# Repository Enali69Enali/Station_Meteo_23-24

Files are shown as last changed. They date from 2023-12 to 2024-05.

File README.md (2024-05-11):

# Station_Meteo_23-24
## Description du projet
Pour le cours de projet d'électronique lors de la 4e année du cycle d'ingénieur en alternance, celui ci réalise une girouette pour la station météo d'une ruche connectée. 
Une girouette est un objet de mesure pour nous donner la direction du vent. Ce projet reprend le projet Github 2022-2023 : [Station_Meteo_2022-2023](https://github.com/Solene49000/Station_Meteo_2022-2023). 
Dans ce projet, leur systeme de girouette n'était pas fonctionnelle, du à des differences de tensions trop faible par rapport au différente position de la fleche de la girouette. Nous proposons donc une solution alternative à ce probleme avec notre projet. 

Ce projet de station météo comporte plusieurs composants tels que:
- La quantité de pluie tombée 
- La vitesse du vent 
- La luminosité
- La température 
- L'humidité
Mais nous nous concentrons surtout sur la direction du vent avec la girouette. 

Pour voir la présentation du projet en cours, cliquez [ici](https://github.com/Enali69Enali/Station_Meteo_23-24/blob/master/rapport_de_s%C3%A9ance/Premier%20pr%C3%A9sentation%20%C3%A9lectronique.pdf).

## Fonctionnement
La première question à laquelle nous avons du repondre est : **Comment connaitre la direction de vent sans utilisé la premiere méthode ?** 
Le difference de tension est une bonne méthode mais devait etre plus importante pour faire fonctionner le projet. 
Nous sommes donc partis sur une idée de CODE GRAY (1 bit se change à la fois) avec 4 entrée. Pour avoir une seule sortie nous avons utilisé un réseau R2R.
### Le projet physique
Pour simuler le CODE GRAY, nous avons pensé à une idée de LED émettrices et photo-transitors récepteurs séparer par un tourniquet fait en impression 3D. Quand il y aura le passage d'un trou (pas de matiere), les photo-transitor recevront la lumière infrarouge. Sinon rien ne sera perçu.
Voici les principales impressions 3D nécessaire pour le projet :
* [Boite maintenant le PCB](https://github.com/Enali69Enali/Station_Meteo_23-24/blob/master/modelisation_3D/boite.stl) (Attention dans le fichier .stl il manque un trou pour faire passer les câbles que nous avons rajoutés en en faisant un dans le fond de la boite avec un fer à souder. Pour les autres modifications regarder [ici](#petits-défaut-à-améliorer-pour-le-bon-fonctionnement-du-projet))
* [Couvercle](https://github.com/Enali69Enali/Station_Meteo_23-24/blob/master/modelisation_3D/cylindre%20led-couvercle.stl) (Attention le PCB a un sens sinon celui ci ne passera pas avec le couvercle)
* [Réajusteur pour le roulement](https://github.com/Enali69Enali/Station_Meteo_23-24/blob/master/modelisation_3D/calle%20roulement.stl)
* Fleche de la girouette nous avait été déja fournis

Pour le montage, il suffit de collé le réajusteur pour le roulement sur la tige de la boite, puis de placé un roulement adapté pour emboité le couvecle et la boite. Les impressions sont fait pour des roulements aux dimensions de : diamètre extérieur 22mm, diamètre intérieur 8mm et diamètre de hauteur 7mm.

En plus a été designé un cache pour séparer LEDs/ photo-transistors les uns des autres (voir [le rapport du jour 13/03 de PELLETIER](https://github.com/Enali69Enali/Station_Meteo_23-24/blob/master/rapport_de_s%C3%A9ance/Rapport13_03_2024PELLETIER.pdf)). Ceux ci n'ont pas encore été testé.

### Le projet électronique
#### Hardware
Le [PCB](https://github.com/Enali69Enali/Station_Meteo_23-24/blob/master/BoardsEAGLE/R2R_v2.1.brd) contenant le réseau R2R doit être imprimés (si vous ne l'avez pas déjà) et ajouté avec chaque composant.
Pour les LEDs et photo-transistors il faut que ceux ci soit soudé au dos de la carte avec la tete reposant sur le plastique du PCB pour être à la même hauteur tous, pour le passage dans le tourniquet soit synchronisé. 
Les LED et phototransistors travaillent sur la même longueur d'onde, cad 940 nm (infrarouge). Les phototransistors sont utilisés en emmeteur commun avec un inverseur MOS à sa sortie afin d'avoir réellement 0 ou 3.3V et pas de valeurs entre pour le bon fonctionnement du réseau R2R. L'angle de réception des phototransistors a été choisi le plus petit possible (et disponible), cad 28º, afin de limiter le plus possible les parasites des autre leds.

#### Software
Un fois téléversé, le programme rentre en light sleep et se réveille toute les 15 secondes (ou si reception d'une goutte de pluie), ce
qui permet d'obtenir la position de la girouette
Il y a 16 position differentes, Ouest etant la plus petite, tous les phototransistors recevant tous de la lumière et Nord etant la plus grande, tous les transistors etant cachés.
Actuellement, le valeurs sont complètement à refaire: la courbe n'étant pas linéaire et les valeurs ayant été déterminées avec le PCB de test, les écarts entre les valeurs sont trop grand et les résultats étaient au final mieux que prévu.
Le code de la girouette reste extrêmement simple, etant juste un else-if

## Installation
Préparer le modèle de la girouette physique avec le PCB à l'intérieur.
Il faut brancher le cable micro USB à l'ordinateur pour pouvoir téléverser le code mais voir aussi les informations envoyées par la girouette
Ensuite il faut alimenter la girouette en 3.3V: le fil rouge doit être branché au 3.3V et le fil noir au GND.
Pour vérifier que le montage fonctionne bien, environs 170 mA sont "consommés" par notre montage et sont donc visible sur le générateur
de tension

## Utilisation
Nous avons decidé pour nos tests que le N serait pointé à la position 0 0 0 0 (tous les phototransistors ne recoivent pas de rayonnement des LEDs).
Lors du lancement du programme, celui ci retournera toutes les 15 secondes la direction de la girouette. Le projet n'a pas encore été testé en rajoutant l'anémomètre.

## Petits défaut à améliorer pour le bon fonctionnement du projet
- Les calles du PCB dans la boite ne sont pas exactement aligné, il faut la bloqué avec du scotch en exemple et la surélever pour que les LEDs/photo-transistors soient au niveau des trous pour laisser le passage des rayons. Conseil : si vous voulez résoudre ce soucis avant l'impression de la boite, vous devez surélever le fond de la boite de 2-3 mm;
- Les valeurs theoriques recues par la carte sont différentes de la réalité, il faut donc réajuster les valeurs pour la bonne gestion de la direction de la girouette;
- Les séparateurs peuvent être imprimés si ils y a trop d'interférence.

## Auteurs et remerciments
Projet réalisé par DUEE-MOREAU Arwen et PELLETIER Ilane en classe ELSE4 cursus Polytech FISA 4 année sur le semestre 7 et 8 avec l'aide du professeur PETER Christian.

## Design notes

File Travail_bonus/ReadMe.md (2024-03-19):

Travail supplémentaire fait en plus du projet.
Sujet principale : Module ESP32 LoRa

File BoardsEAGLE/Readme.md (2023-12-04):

Ici sont stockées les dessin cartes (schematics, boards).

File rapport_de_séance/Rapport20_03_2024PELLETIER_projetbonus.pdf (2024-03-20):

# Rapport de séance n°13

Séance spéciale : aide pour un autre groupe

Séance du 20/03/2024

## Objectif de la séance : Réalisation des modèles 3D

Continuer sur le travail bonus en attendant notre carte.

## Réalisé pendant la séance

Notre problème semble venir de l’initialisation du récepteur qui sors une erreur lors de la fonction begin(). Nous avons changé les programmes émetteur et récepteur (trouvé directement dans les exemple fourni sur l’application Arduino).

https://forum.arduino.cc/t/lora-modulefails-on-first-time-init/1015518 (https://forum.arduino.cc/t/lora-module-fails-on-first-time-init/1015518)

Nous avons remarqué que les pins n’était pas initialisé donc nous les initialisons.

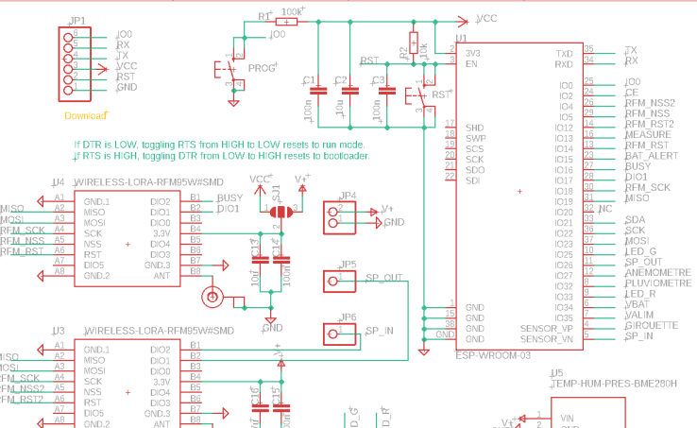
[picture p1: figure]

En initialisant, le Sender fonctionne mais pas de Receiver.

Documentation eps32 :
https://www.espressif.com/sites/default/files/documentation/esp32-wroom-32_datasheet_en.pdf. (https://www.espressif.com/sites/default/files/documentation/esp32-wroom-32_datasheet_en.pdf)

Documentation LoRa CC68 :
https://www.manualslib.com/manual/2618644/Nicerf-Lora-Cc68.html?page=5#manual. (https://www.manualslib.com/manual/2618644/Nicerf-Lora-Cc68.html?page=5#manual)

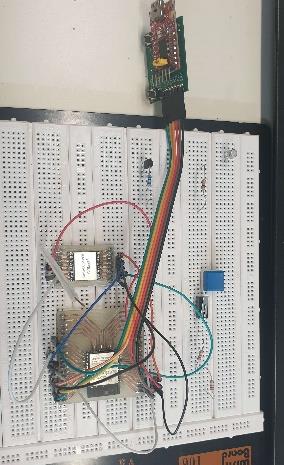
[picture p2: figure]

Avec les documentations si dessus j’ai pu rebrancher les modules (voir photo). Après avoir bien remis le RX et TX, nous téléversons le code du récepteur. Malheureusement nous retombons sur notre erreur d’initialisation « Starting LoRa failed ! ». Nous devons surement avoir un soucis dans l’initialisation des pins.

## Problèmes de la séance

Problème avec le petit PCB pour remplacer le module LoRa causant une erreur lors du téléversement du code.

## A faire attention

Bien branché le mini USB. Mettre la même fréquence en émission et réception.

## A faire à la prochaine séance

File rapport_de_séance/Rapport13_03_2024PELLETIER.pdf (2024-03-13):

# Rapport de séance n°11

Séance du 13/03/2024

## Objectif de la séance : Réalisation des modèles 3D

Finir le PCB et l’envoyer, designer le cache.

## Réalisé pendant la séance

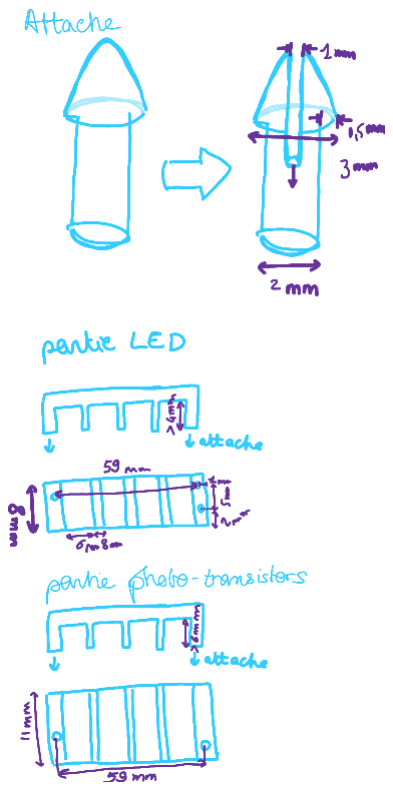
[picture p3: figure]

J’ai commencé la séance par terminer le PCB pour pouvoir le faire imprimer rapidement.

J’ai finis de redécaler les emplacement de LEDs et phototransistors pour pouvoir caller les composants au dos du PCB « collé ». J’ai également placer les trous pour fixer les caches.

Nous avons générer les fichiers geber pour pouvoir envoyer à l’usine la fabrication de notre PCB.

Passons au cache sur FreeCad.

J’ai pensé à un système d’attache pour fixer le cache au-dessus des LEDs ou des phototransistors.

Apres avoir pris toutes les mesures j’ai pu commencer la modélisations des caches.

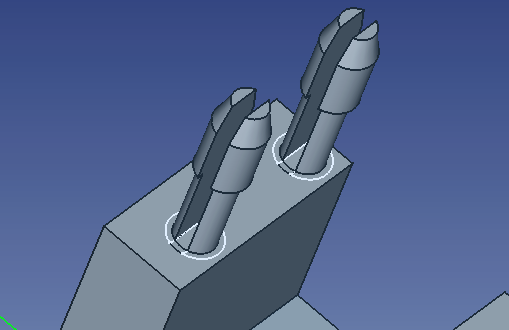
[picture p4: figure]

Vous pouvez retrouvez ces pièces en fichiers .stl directement sur GitHub.

## Problèmes de la séance

## A faire attention

Les attaches sont seulement faites en théorie, jamais tester en conditions réelles.

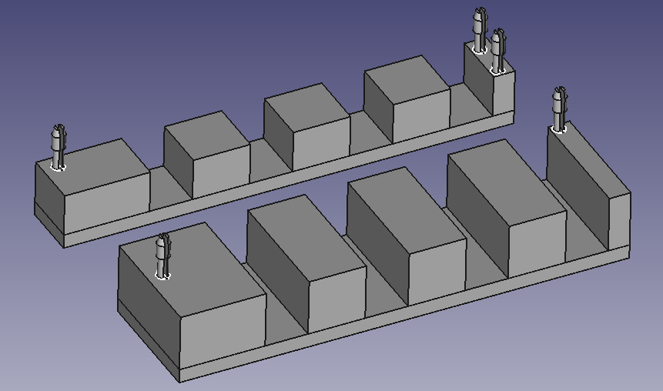
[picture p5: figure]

## A faire à la prochaine séance

Imprimer les caches et trouer la boite (que nous avons oublier de trou pour faire passer le câble.

Si nous avons reçu le composant nous pourrons aussi souder sur le PCB les composants.

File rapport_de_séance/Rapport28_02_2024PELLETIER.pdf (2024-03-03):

# Rapport de séance n°10

Séance du 28/02/2024

## Objectif de la séance : Réalisation des modèles 3D

Récupérer les impressions 3D, finir le dessin Layout et faire le design 3D cache.

## Réalisé pendant la séance

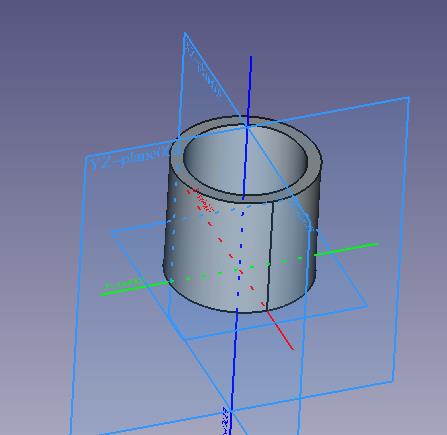
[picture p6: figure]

Au début de la séance j’ai récupéré les impressions 3D finit et passer un peu de temps a retirer les supports (long car il y avait des supports pour chaque interstice de LED). Dans le couvercle, le roulement c’est parfaitement emboité ((on ne peut plus le retirer). Malheureusement, j’ai étais trop prévoyant pour la boite et il y avait trop de jeu entre la tige et le roulement.

J’ai donc designer et imprimer une nouvelle petite pièce pour empêcher cet écart.

Apres l’impression, je l’ai colle avec la colle chaude sur le pic principal de la boite.

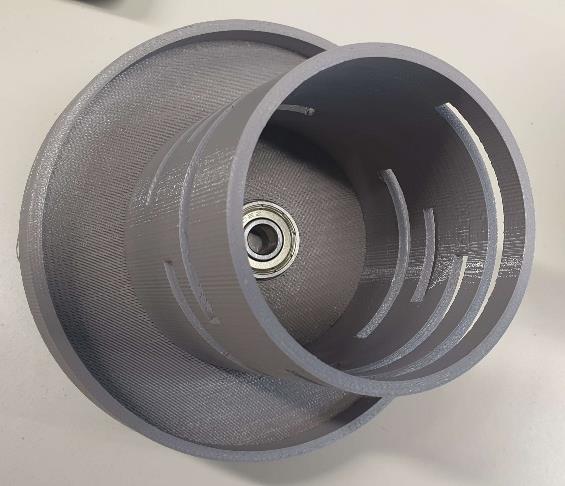
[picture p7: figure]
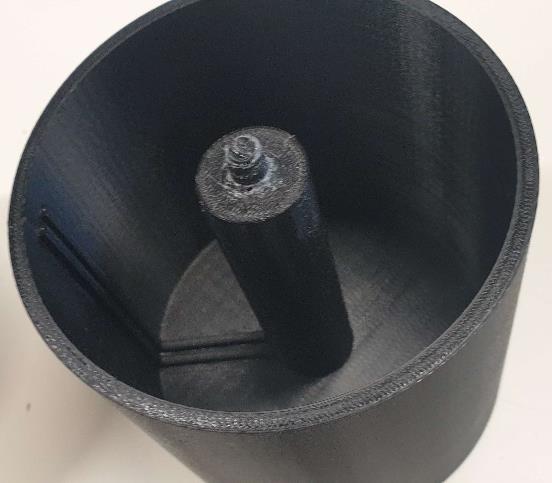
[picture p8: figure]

J’ai également retravailler la pointe qui permet de
fixer la girouette avec une soufflette d’air chaud (car celle-ci c’était déformé lors de l’impression a cause du poids et de la chaleur).

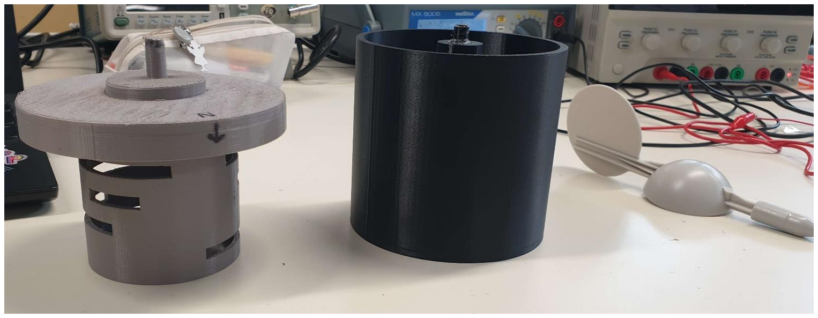
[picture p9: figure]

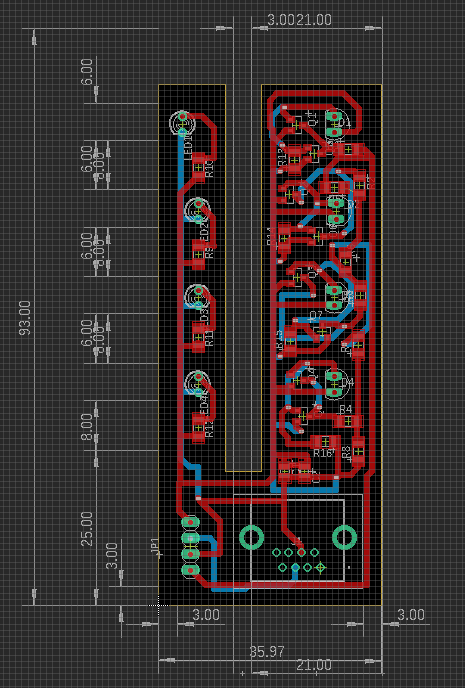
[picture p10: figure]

Apres avoir finit de travailler les impressions, je me suis remis sur le design du Lay-out du PCB du réseaux R2R.

J’ai finit par arriver a ce résultat, en faisant attention entre la distance des chemin et le placement des LEDs/phototransistors.

J’ai rajouté les trous dans le PCB et souder des éléments pour que ma camarade avance.

## Problèmes de la séance

N’aies pas eu beaucoup de temps pour travailler sur le cache.

## A faire attention

Ne pas oublier les trous dans le PCB.

## A faire à la prochaine séance

Finir le PCB et l’envoyer, designer le cache.

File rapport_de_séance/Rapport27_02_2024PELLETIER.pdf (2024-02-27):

# Rapport de séance n°10

Séance du 27/02/2024

## Objectif de la séance : Réalisation des modèles 3D

Récupérer les valeurs des dimensions des roulements pour modifier les impressions 3D en conséquences et pouvoir imprimer et continuer voire finir le design du PCB.

## Réalisé pendant la séance

Durant la séance, j’ai pu finir la modélisation des pièces (boite et couvercle) avec les mesures du nouveau roulement.

Apres avoir fait ces modifications, j’ai lancé les impressions qui seront normalement finies pour le prochain cours.

Je me suis remis sur la modification du layout avec les nouveau distances du PCB.

Nous avons une largeur maximale de 36mm.

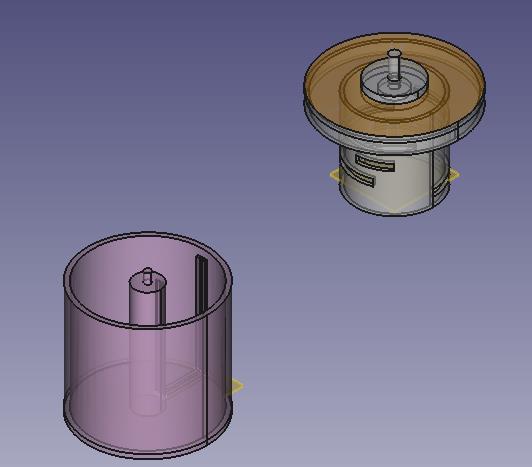
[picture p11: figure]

En étudiant la question, nous devrons « coller » les LEDs et phototransistors d’un cote de la carte et les composants de l’autre.

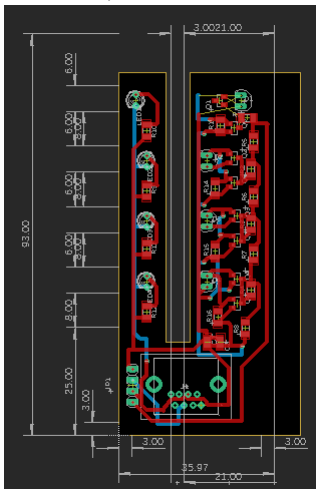
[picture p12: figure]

## Problèmes de la séance

Ne pas avoir laisser assez d’espace pour le placement des LEDs et phototransistors.

## A faire attention

De même.

## A faire à la prochaine séance

Finir le dessin Layout et faire le design 3D cache.

Diamètre extérieur | 22 mm
Diamètre intérieur | 8 mm
Hauteur | 7 mm

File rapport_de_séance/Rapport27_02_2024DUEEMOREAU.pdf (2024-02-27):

Comme les problèmes de la séance précédente ont été résolu (en par4e), j’ai pu réaliser les mesures.
Nous obtenons ce tableau :

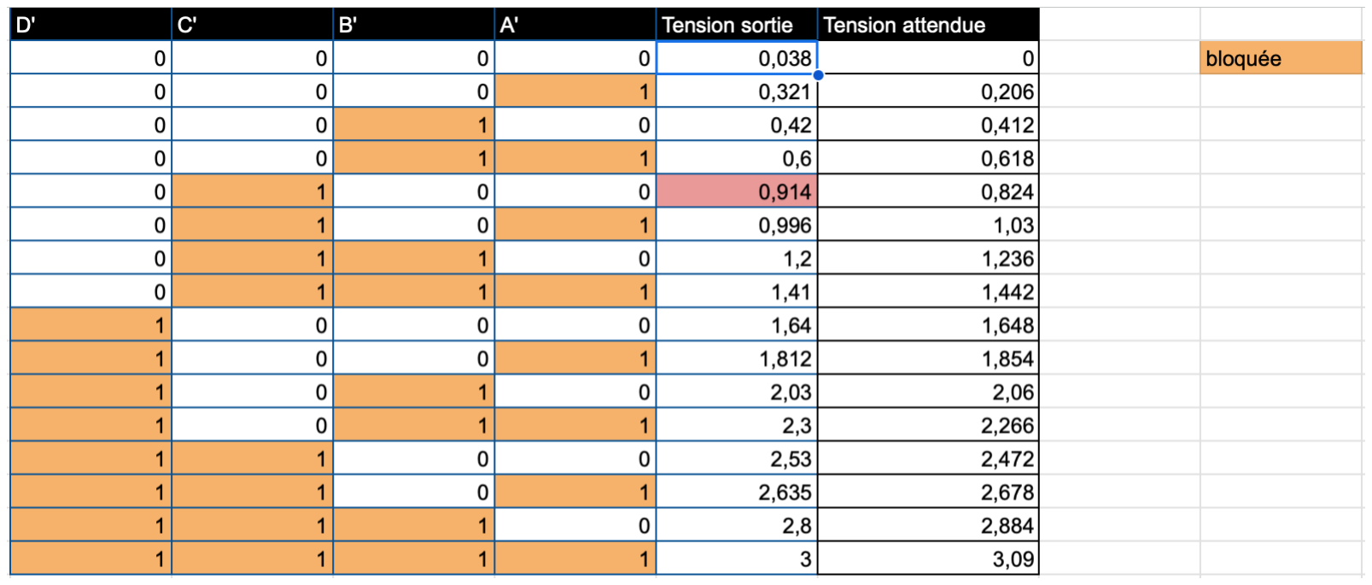
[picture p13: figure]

La led A étant le lsb et la D le msb.

Les valeurs obtenues sont légèrement différentes à cause des problèmes de soudure. Nous pouvons donc en conclure que le réseau marche pour notre projet.

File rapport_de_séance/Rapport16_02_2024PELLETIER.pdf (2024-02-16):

# Rapport de séance n°9

Séance du 16/02/2024

## Objectif de la séance : Réalisation des modèles 3D

Récupérer l’impression 3D, retravailler le PCB.

## Réalisé pendant la séance

L’impression terminée, j’ai retiré tous supports créer pour l’impression. Puis comme le plateau a été imprimer avec des supports j’ai utilisé une soufflette chauffante pour faire refondre le dessus pour permettre sa fixation. Le rendu n’est pas parfait mais celui-ci tient.

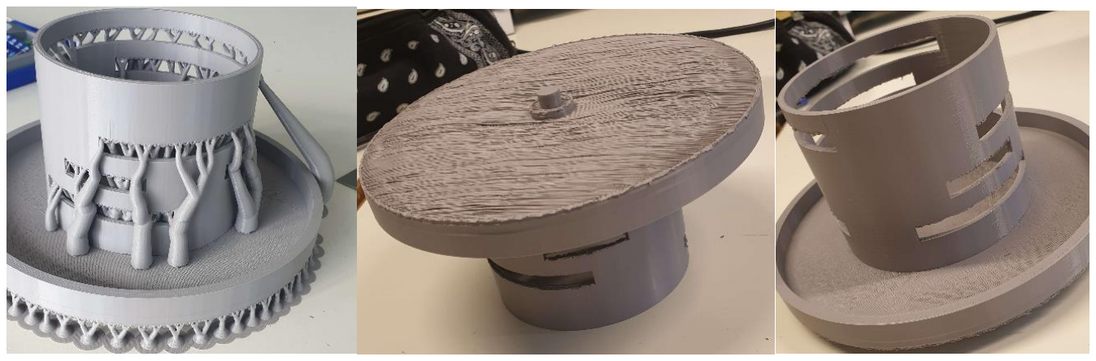
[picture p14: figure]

Malheureusement, en sorti d’impression nous nous rendons compte :

- De sa taille par rapport au système. Celui-ci est surement un peu trop grand en largeur. Nous réduirons donc certains paramètres de taille pour la prochaine impression ;
- Qu’il faudra utiliser un roulement plus gros pour supporter le système ;
- Que la queue de la girouette ne passe pas en hauteur.

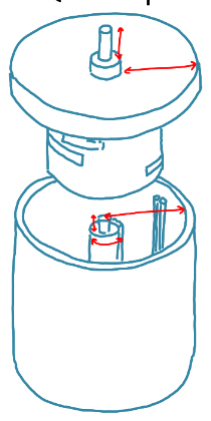
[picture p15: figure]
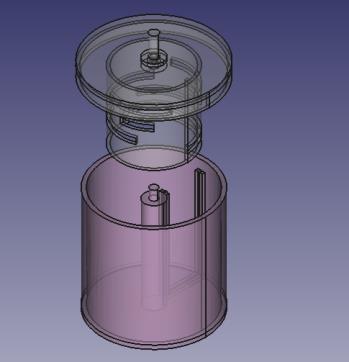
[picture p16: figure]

Les fichiers modifiés ont été ajouté sur le Github du projet.

J’ai également commencé à modifier les dimensions du PCB sur EAGLE.

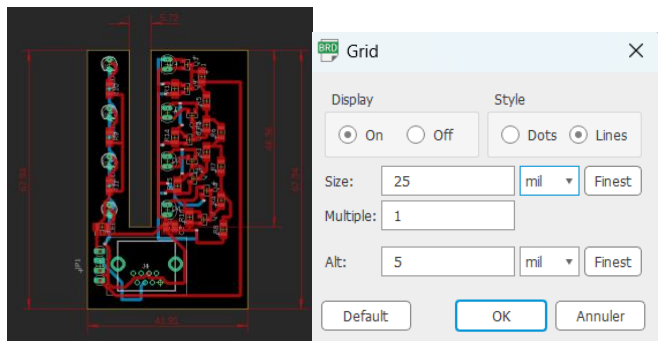
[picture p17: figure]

Avant :

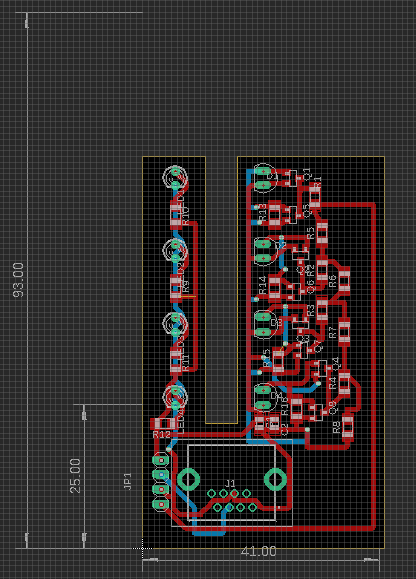
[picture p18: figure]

Début de la prise de mesure :

## Problèmes de la séance

Un composant du PCB test ne fonctionnais pas donc j’ai du resouder certains composant pour aider ma camarade à avancer sur les tests.

## A faire attention

Au soudure qui se défont rapidement sur ce PCB test, à la taille du roulement pour l’impression et à l’unité lors du design sur la board EAGLE.

## A faire à la prochaine séance

Récupérer les valeurs des dimensions des roulements pour modifier les impressions 3D en conséquences et pouvoir imprimer et continuer voire finir le design du PCB.

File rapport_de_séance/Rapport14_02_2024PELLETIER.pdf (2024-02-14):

# Rapport de séance n°8

Séance du 14/02/2024

## Objectif de la séance : Réalisation des modèles 3D

Lancer l’impression 3D, test.

## Réalisé pendant la séance

Après avoir tester, nous nous sommes aperçu avec l’aide de notre professeur que la LED n’avait pas assez de courant pour émettre avec 3V3. Notre résistance était initialement à 100kΩ.

Les tests réalisés :

Valeurs de résistances | 100kΩ | 47Ω | 33kΩ
Avec émission de la LED | 3.22 V | 3.2 V | 3.24 V
Sans réception de photorécepteurs | 0.2 V | 0.008 V | 0.006 V

Nous choisissons la 33kΩ car elle nous affiche des résultats satisfaisant (proche de3V3) et que nous en avons en stocks.

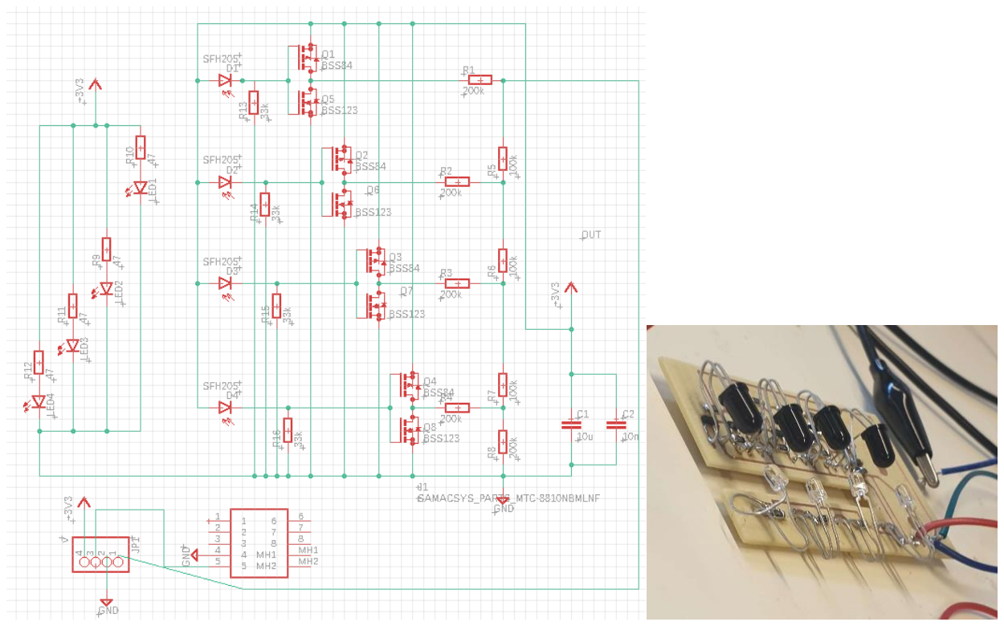
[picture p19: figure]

Un problème supplémentaire qui s’est rajouté que nous n’avions pas remarqué avant : les vias de ce PCB ne sont pas métallisé. J’ai donc du couper des pattes de composant pour combler les trous et donc relier la partie supérieur de la carte avec celle inférieur.

Après avoir tout resouder, nous avons tester et nous avons 3.0V et 0.3V.

## Problèmes de la séance

Une partie de la piste c’est dessoudé, j’ai dû donc m’arranger pour tirer la patte d’une LED pour combler le manque.

## A faire attention

## A faire à la prochaine séance

Tester la première impression 3D

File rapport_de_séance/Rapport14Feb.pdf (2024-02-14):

Pendant la séance, nous avons dû revoir les valeurs des résistances du PCB.
Nous avons remarqué que nous avions mis 100k Ohms au niveau des diodes au lieu de 230 Ohms, ce qui faisait que le courant dans la diode était trop faible (qui devait être de 100 mA). Nous avons finalement uHlisé 47 Ohms afin d’avoir 100 mA dans les diodes.

Coté phototransistor, nous avons aussi réajustés la résistance à l’émeNeur pour passer de 100k à 33k car les résultats obtenus sur la plaque à trous étaient meilleurs. On devait être sur que les tensions de seuils des transistors P et N étaient aNeint avec la nouvelle valeur de résistance.

Le schéma diode-transistor est donc :

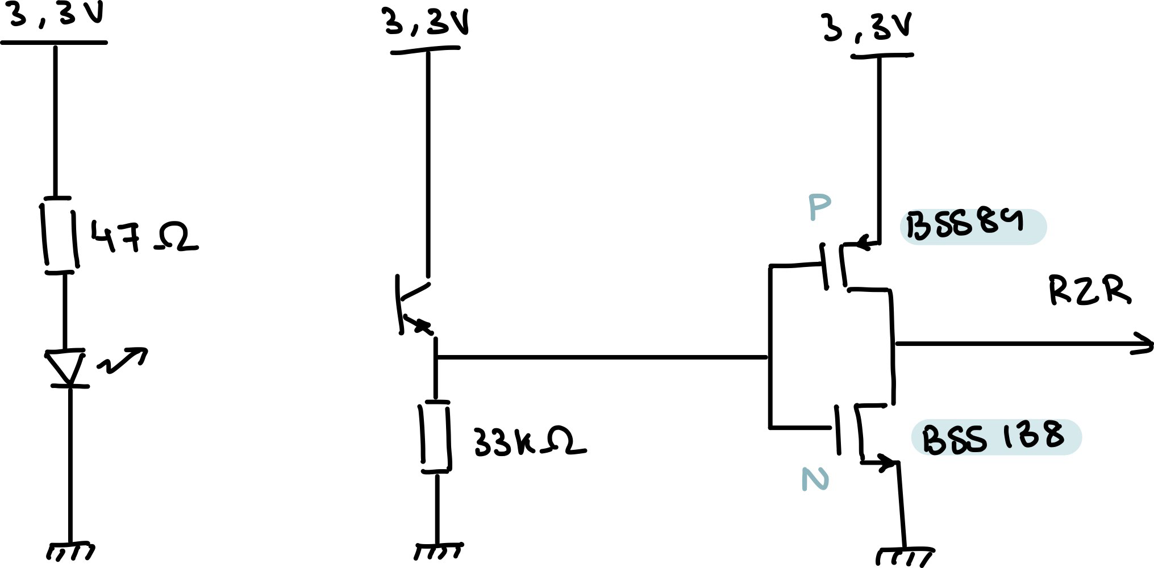
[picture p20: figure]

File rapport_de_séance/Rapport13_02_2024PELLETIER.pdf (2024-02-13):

# Rapport de séance n°7

Séance du 13/02/2024

## Objectif de la séance : Réalisation des modèles 3D

Souder sur le PCB les composants du schéma et faire la soutenance de milieu de projet.

## Réalisé pendant la séance

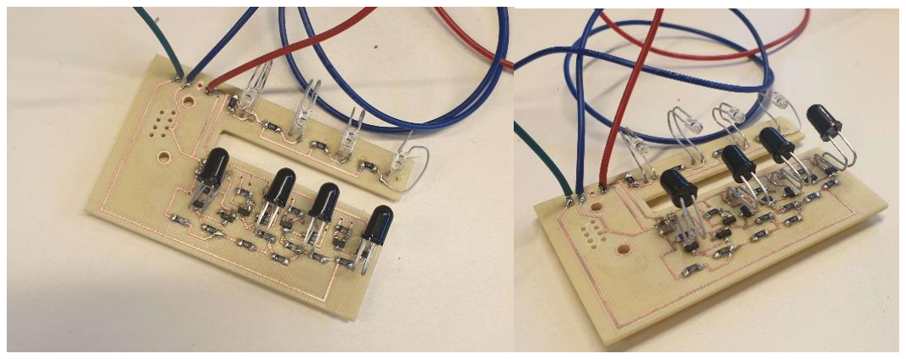
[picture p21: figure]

J’ai pu souder les composant en faisant attention au composant et leur valeur. C’était un travail long et minutieux. Il fallait aussi faire attention au sens des LED et capteurs infrarouges.

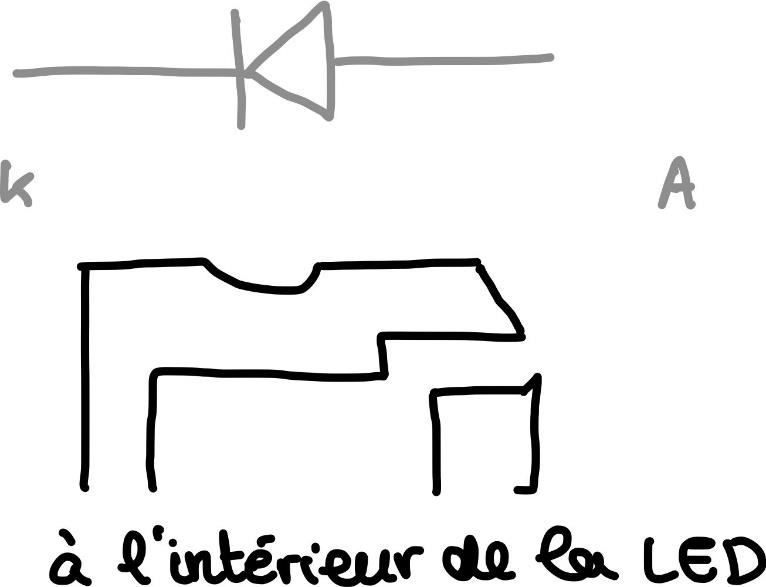
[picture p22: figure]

## Problèmes de la séance

Une partie de la piste c’est dessoudé, j’ai dû donc m’arranger pour tirer la patte d’une LED pour combler le manque.

## A faire attention

## A faire à la prochaine séance

Tester et mettre a imprimer la première pièce en 3D.

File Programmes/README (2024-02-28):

Fichiers du projet précédent avec les modifications apportées par notre groupe cette année

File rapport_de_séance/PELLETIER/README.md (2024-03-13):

Rapport de séance de l'étudiant Ilane PELLETIER.

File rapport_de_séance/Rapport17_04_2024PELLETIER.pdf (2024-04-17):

# Rapport de séance n°15

Séance du 17/04/2024

## Objectif de la séance : Réalisation des modèles 3D

Aider Arwen avec les tests puis commencer a faire les slides.

## Réalisé pendant la séance

Malheureusement, à la dernière séance, il y avait des petits soucis de transmission. A l’aide de pate a modeler nous avons pu déterminer que la carte était trop basse par rapport au fente du code gray (mettre la pate a modeler sur la fente de la carte puis mettre le couvercle, celle-ci laisse une marque de la hauteur de la fente). Nous avons du nous y prendre de cette manière car la boite totalement opaque nous empêchera de savoir son placement interne.

Nous avons vu qu’il nous manquait 2 mm de hauteur, donc nous l’avons rehausser avec du scotch plié.

Le reste de la séance, je l’ai consacré a commencer les slides de la présentation finale.

## Problèmes de la séance

## A faire attention

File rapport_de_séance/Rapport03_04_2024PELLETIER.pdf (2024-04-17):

# Rapport de séance n°14

Séance du 03/04/2024

## Objectif de la séance : Réalisation des modèles 3D

Souder et monter notre girouette.

## Réalisé pendant la séance

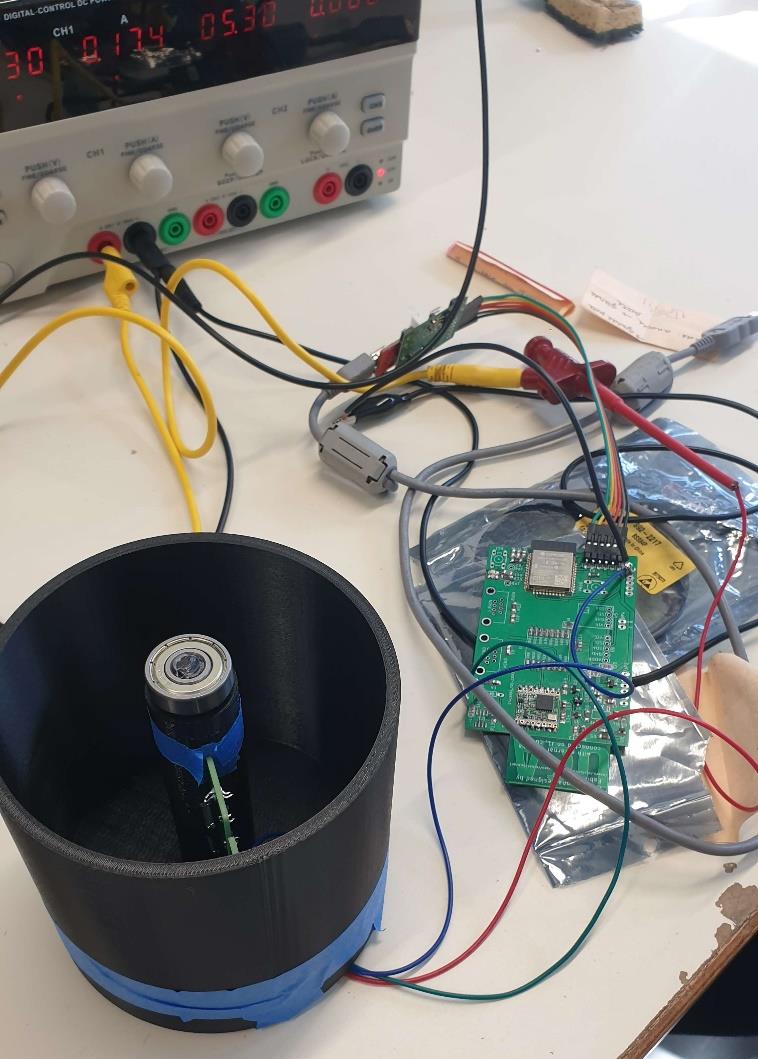
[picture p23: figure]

Après que la pâte thermique soit positionner sur le PCB par le professeur, j’ai installé les composant 1 à 1 pour passer la carte au four.

Sortie du four, j’ai installé les composants LEDs et photo-transistors et je les soudé.

(en m’assurant que ceci soit face a face)

Arwen a testé le système, puis je l’ai installé dans la boite dans laquelle j’ai fait un trou.

Malheureusement, il y a des petits soucis de transmission que nous règlerons a la prochaine séance.

## Problèmes de la séance

Soucis dans la dernière étape.

## A faire attention

## A faire à la prochaine séance

Faire fonctionner le tout.

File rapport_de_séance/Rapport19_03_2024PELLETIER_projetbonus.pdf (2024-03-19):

# Rapport de séance n°12

Séance spéciale : aide pour un autre groupe

Séance du 19/03/2024

## Objectif de la séance : Réalisation des modèles 3D

Comme je ne pouvais pas avancer sur notre projet car nous n’avions pas la carte pour commencer les premier test, j’ai commencé à rédiger un script pour un autre groupe de projet : des scripts pour des ESP32 avec modulo LoRa.

## Réalisé pendant la séance

Avec des documentations d’internet (https://randomnerdtutorials.com/ttgo-lora32-sx1276-arduinoide/) (https://randomnerdtutorials.com/ttgo-lora32-sx1276-arduino-ide/) et nos propres codes déjà fournis dans notre projet j’ai pu commencer à écrire.

Etape 1 : Initialisation des modules (pris du projet de l’année dernière de la station météo)

Etape 2 : connexion au module (choisir le bon port)

Etape 3 : Test d’envoi d’une string

Plusieurs problèmes sont arrivés a partir de cet instant, je suis arrivé à recevoir quelques caractère mais ne correspondant pas forcément à ceux envoyé puis je ne recevais plus rien. En ajoutant des logs pour savoir ou es ce que je me situe, j’ai pu remarqué que je me situais bloqué a la fin d’une fonction. J’ai l’impression que les module n’arrive pas à se connecter entre eux.

Les codes ont été posés sur GitHub dans le dossier Travail_bonus/.

## Problèmes de la séance

Problèmes cités au-dessus

## A faire attention

## A faire à la prochaine séance

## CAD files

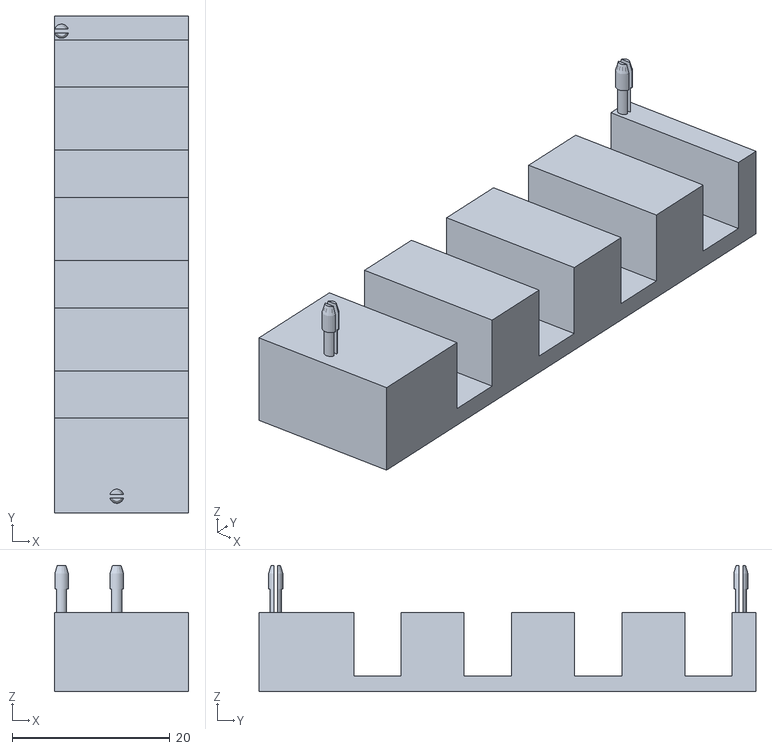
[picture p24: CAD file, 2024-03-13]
modelisation_3D/cylindre led-cache ptT.stl
17.0 x 63.0 x 16.0

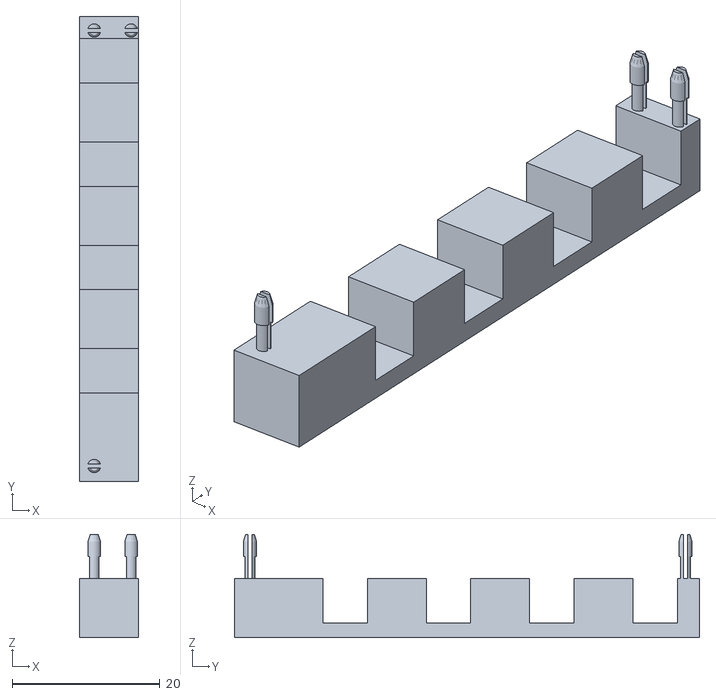
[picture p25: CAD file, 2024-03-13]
modelisation_3D/cylindre led-cache LED.stl
8.00 x 63.0 x 14.0

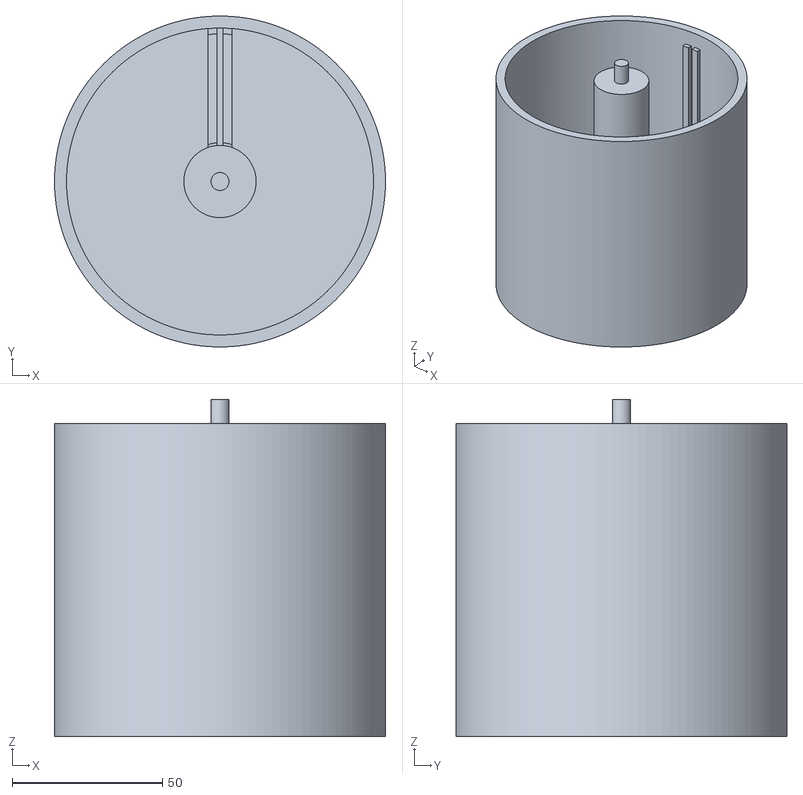
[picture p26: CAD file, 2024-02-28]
modelisation_3D/boite.stl
110.0 x 110.0 x 112.0

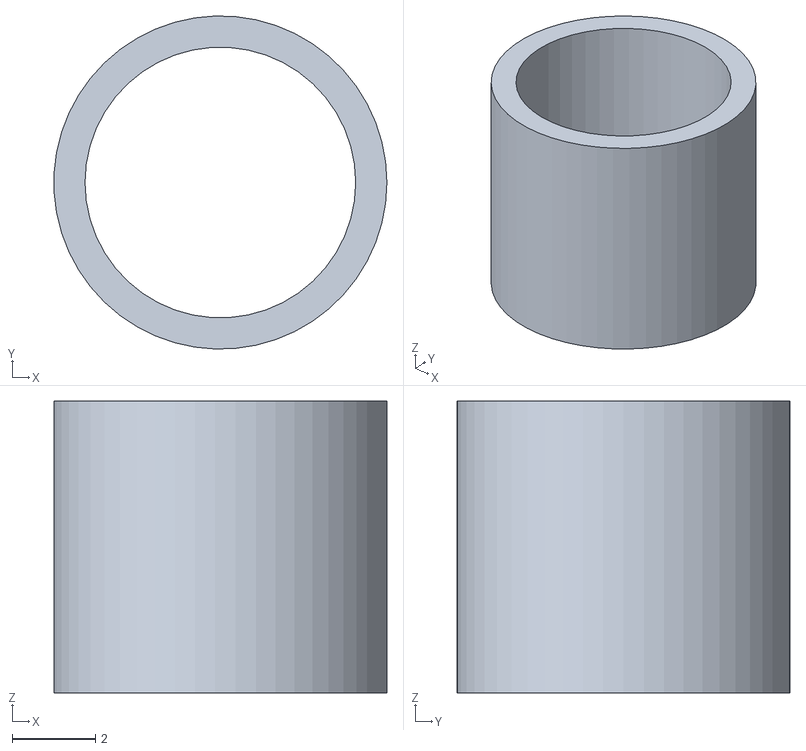
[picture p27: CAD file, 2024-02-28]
modelisation_3D/calle roulement.stl
7.99 x 8.00 x 7.00

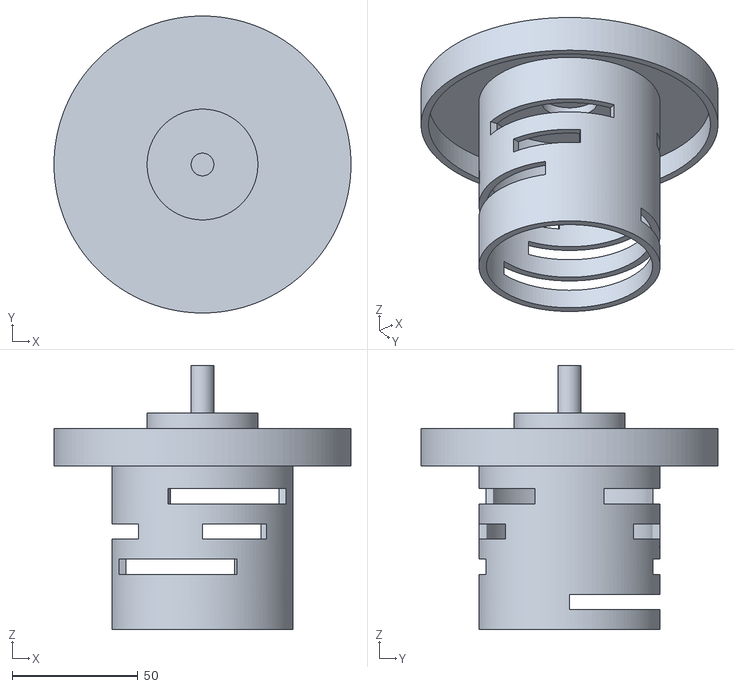
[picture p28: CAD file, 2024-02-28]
modelisation_3D/cylindre led couvercle.stl
118.0 x 118.0 x 105.0

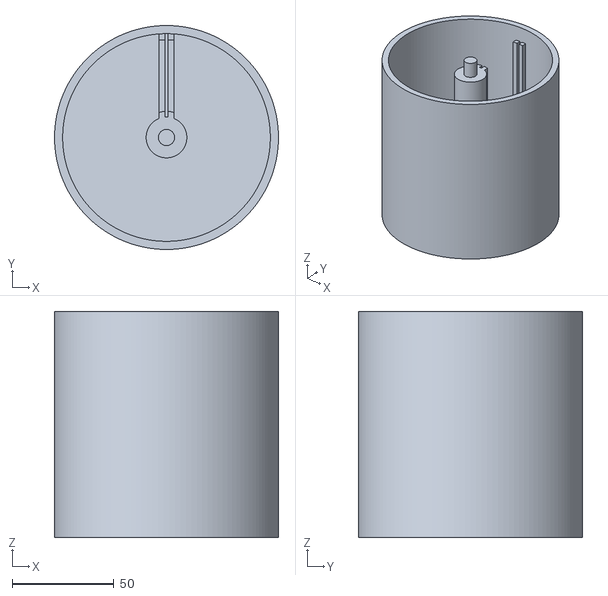
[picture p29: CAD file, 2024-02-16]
modelisation_3D/cylindre led-boite.stl
110.0 x 110.0 x 111.0

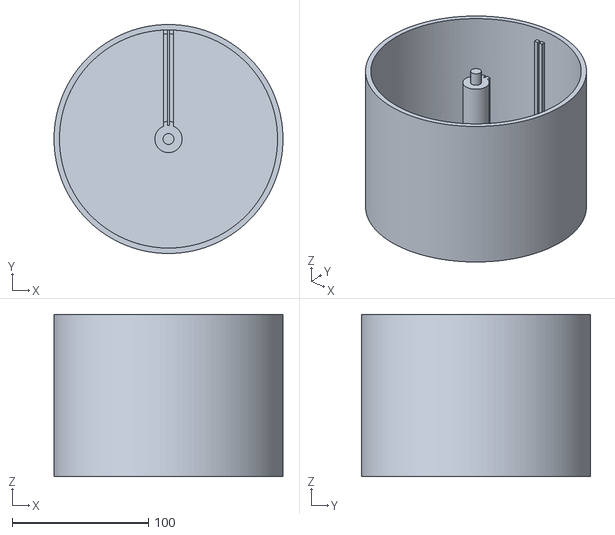
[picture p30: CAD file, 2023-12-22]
modelisation_3D/boite pcb-Body.stl
168.0 x 167.9 x 119.0

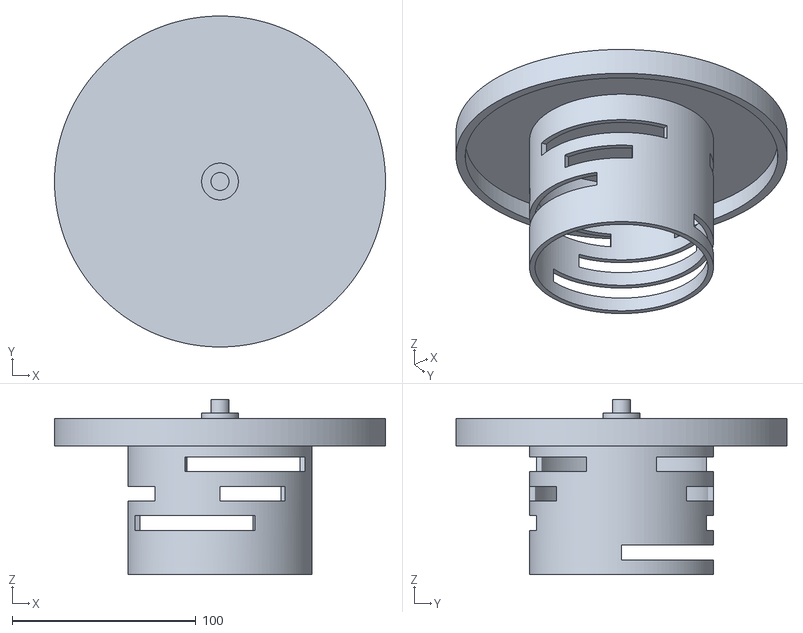
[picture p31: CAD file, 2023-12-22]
modelisation_3D/couvercle cylindre led-Body.stl
180.0 x 179.9 x 95.2

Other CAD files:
modelisation_3D/v2_modelisation_grille_code_gray.stl
modelisation_3D/v1_modelisation_grille_code_gray.stl
modelisation_3D/cylindre led-couvercle.stl

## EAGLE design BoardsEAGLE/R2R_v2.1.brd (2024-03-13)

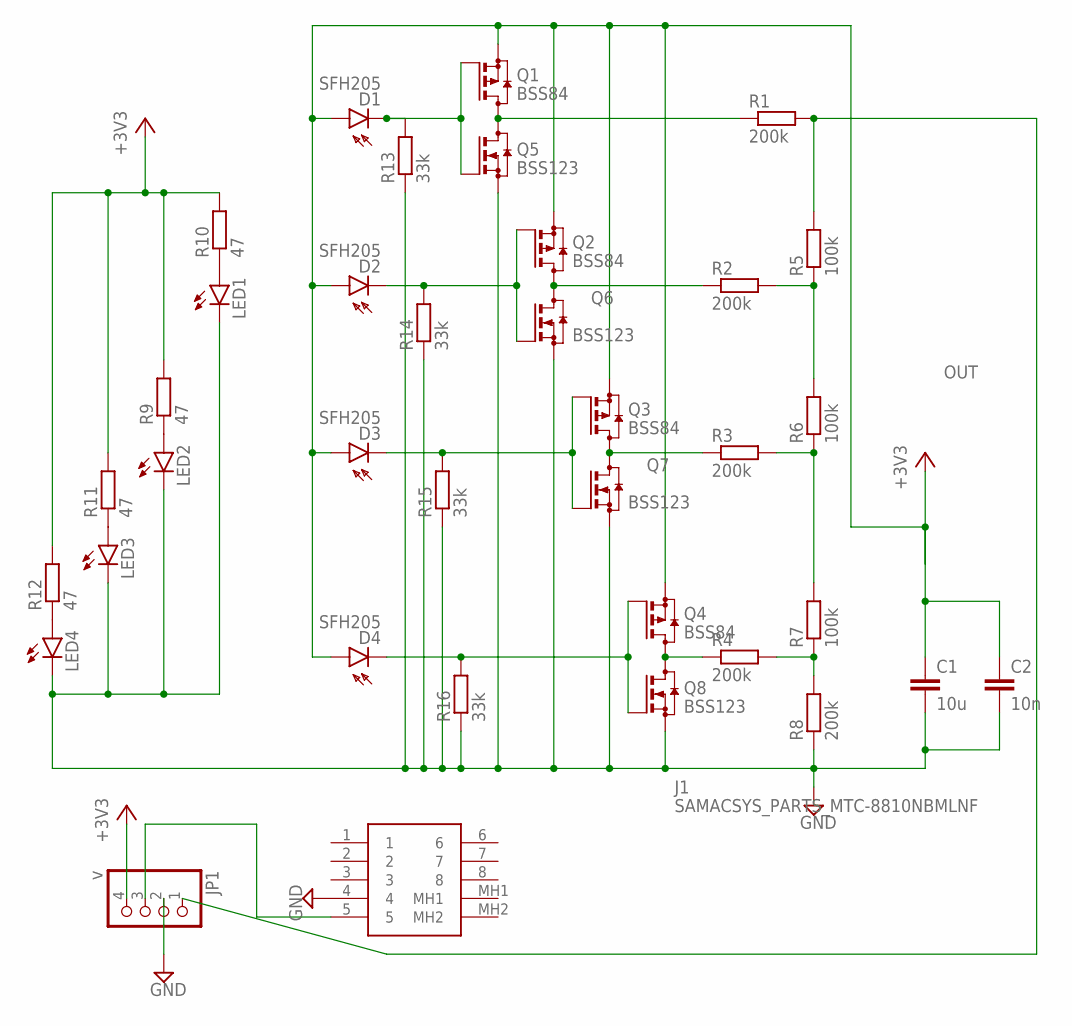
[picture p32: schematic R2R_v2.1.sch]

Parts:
C1: 10u; C0805
C2: 10n; C0805
D1, D2, D3, D4: SFH205
J1: SAMACSYS_PARTS_MTC-8810NBMLNF; SAMACSYS_PARTS_MTC8810NBMLNF
JP1: v; 1X04
LED1, LED2, LED3, LED4: LED3MM
Q1, Q2, Q3, Q4: BSS84; SOT23
Q5, Q6, Q7, Q8: BSS123; SOT23
R1, R2, R3, R4, R8: 200k; R1206
R5, R6, R7: 100k; R1206
R9, R10, R11, R12: 47; R1206
R13, R14, R15, R16: 33k; R1206

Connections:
+3V3: C1.1, C2.1, D1.A, D2.A, D3.A, D4.A, JP1.4, Q1.2 (S), Q2.2 (S), Q3.2 (S), Q4.2 (S), R9.2, R10.2, R11.2, R12.2
GND: C1.2, C2.2, J1.4, JP1.2, LED1.K (C), LED2.K (C), LED3.K (C), LED4.K (C), Q5.2 (S), Q6.2 (S), Q7.2 (S), Q8.2 (S), R8.1, R13.1, R14.1, R15.1, R16.1
unnamed: Q1.3 (D), Q5.3 (D), R1.1
unnamed: R2.2, R5.1, R6.2
unnamed: R3.2, R6.1, R7.2
unnamed: R4.2, R7.1, R8.2
unnamed: D4.K (C), Q4.1 (G), Q8.1 (G), R16.2
unnamed: Q3.3 (D), Q7.3 (D), R3.1
unnamed: D2.K (C), Q2.1 (G), Q6.1 (G), R14.2
unnamed: D1.K (C), Q1.1 (G), Q5.1 (G), R13.2
unnamed: LED1.A, R10.1
unnamed: LED2.A, R9.1
unnamed: LED3.A, R11.1
unnamed: LED4.A, R12.1
unnamed: Q2.3 (D), Q6.3 (D), R2.1
unnamed: J1.5, JP1.3
unnamed: D3.K (C), Q3.1 (G), Q7.1 (G), R15.2
unnamed: Q4.3 (D), Q8.3 (D), R4.1
OUT: JP1.1, R1.2, R5.2

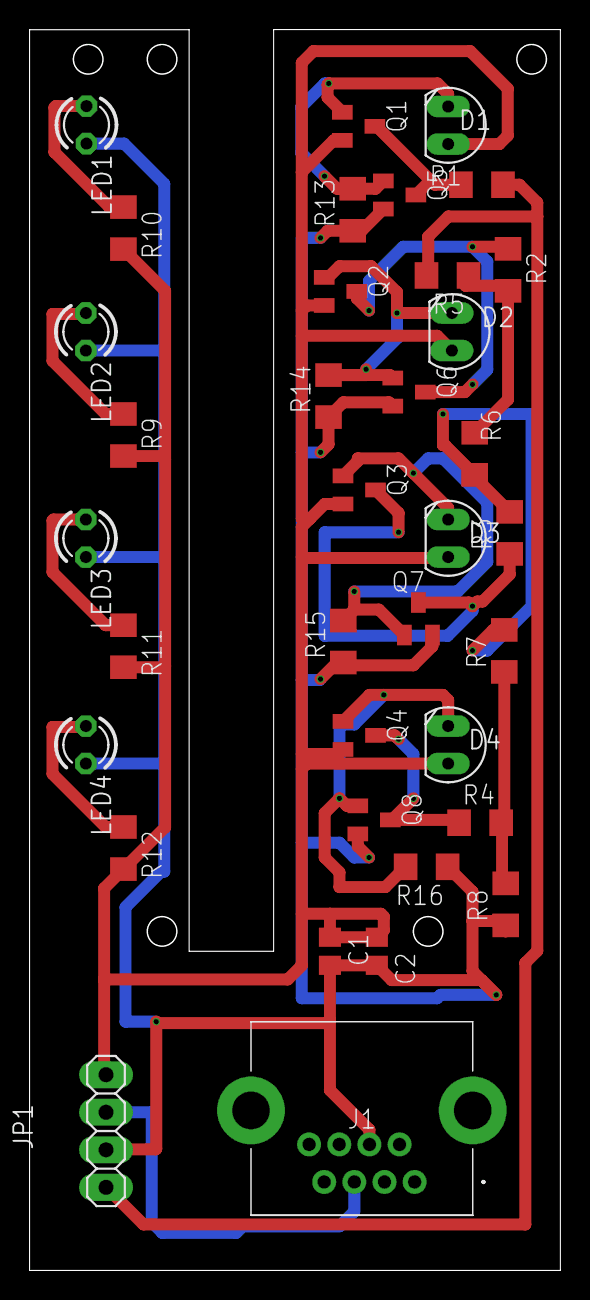
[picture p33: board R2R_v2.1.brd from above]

Board: 2 copper layers, 35.9 x 83.9 mm, 36 parts (0 on the bottom side), 19 nets.

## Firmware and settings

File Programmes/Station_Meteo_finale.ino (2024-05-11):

//PROJET STATION METEO
//AMBRE ALLOUIS - SOLENE GUILLAUME
//ANNEE 2022-2023


//LIBRARIES
#include <Adafruit_BusIO_Register.h>
#include <Adafruit_I2CDevice.h>
#include <Adafruit_I2CRegister.h>
#include <Adafruit_SPIDevice.h>
#include <Adafruit_BME280.h>
#include <Adafruit_Sensor.h>
#include "Adafruit_TSL2591.h"
#include <ESP32TimerInterrupt.h>
#include <ESP32TimerInterrupt.hpp>

//#include "definition.h"
#include "donnees.h"
#include "esp_lora.h"
#include "WiFi.h"

//PINNING DE L'ESP
#define MEASURE 13
#define LED_R 33
#define LED_G 25
#define ANEMOMETRE 27
#define PLUVIOMETRE 32
#define GIROUETTE 36

Adafruit_BME280 bme;
Adafruit_TSL2591 tsl = Adafruit_TSL2591(2591);

//void calculateValues_BME_TSL();
//void printValuesSerial();

//VARIABLES GLOBALES
#define RAYON 0.07 // rayon de l'anemometre de 7 cm
//#define B1000000 64
//#define B110 6
#define uS_TO_S_FACTOR 1000000  /* Conversion factor for micro seconds to seconds */
#define TIME_TO_SLEEP  15        /* Time ESP32 will go to sleep (in seconds) A multiplier par 60 pour 15 minutes */

int compt=0 ;
float quantiteEau = 0;
RTC_DATA_ATTR unsigned long startTime_P = 0;  
RTC_DATA_ATTR unsigned long currentTime_P = 0;
const unsigned long period_P = 10000;

float temperature = 0.0;
float pression = 0.0;
float humidite = 0.0;
float luminosite = 0.0;
float vitesseVent;

int tourAnemo=0 ;
unsigned long startTime_A;  
unsigned long currentTime_A;
unsigned long delayTime;
const unsigned long period_A = 10000;

RTC_DATA_ATTR int nb_wakeup = 0;

void print_wakeup_reason(){
  esp_sleep_wakeup_cause_t wakeup_reason;

  wakeup_reason = esp_sleep_get_wakeup_cause();

  switch(wakeup_reason)
  {
    case ESP_SLEEP_WAKEUP_EXT0 : Serial.println("Wakeup caused by pluviometre"); break;
    case ESP_SLEEP_WAKEUP_TIMER : Serial.println("Wakeup caused by timer"); break;
    default : Serial.printf("Wakeup was not caused by deep sleep: %d\n",wakeup_reason); break;
  }
}

void setup() {
  //Supply ON
  pinMode(MEASURE, OUTPUT);
  digitalWrite(MEASURE, HIGH);
  //Serial monitor port
  Serial.begin(9600);
  //Pin definition
  pinMode (LED_R, OUTPUT);
  pinMode (LED_G, OUTPUT);
  pinMode (ANEMOMETRE, INPUT);
  pinMode (PLUVIOMETRE, INPUT);
  pinMode (GIROUETTE, INPUT);
  //Luxmetre
  bme.begin(0x76);
  tsl.begin(0x76);
  tsl.setGain(TSL2591_GAIN_MED); 
  tsl.setTiming(TSL2591_INTEGRATIONTIME_300MS);
  // LoRa
  SPI.begin(SCK, MISO, MOSI);
  LoRa.setPins(SS, RST, DI0);
  //Interrupts
  attachInterrupt(PLUVIOMETRE,comptage,FALLING);
  attachInterrupt(ANEMOMETRE,comptageAnemo,FALLING) ; 
  //Variable definition
  startTime_P = startTime_P + millis();
  lecture_donnee();
  //wakeup
  //Increment boot number and print it every reboot
  ++nb_wakeup;
  Serial.println("Boot number: " + String(nb_wakeup));
  //Print the wakeup reason for ESP32
  print_wakeup_reason();

  /*  First we configure the wake up source  We set our ESP32 to wake up every 5 seconds  We set our ESP32 to wake up every rain interruption  */
  esp_sleep_enable_timer_wakeup(TIME_TO_SLEEP/10.0 * uS_TO_S_FACTOR);
  Serial.println("Setup ESP32 to sleep for every " + String(TIME_TO_SLEEP) +
  " Seconds");
  esp_sleep_enable_ext0_wakeup(GPIO_NUM_32, 0);
  
  Serial.println("Going to sleep now");
  
  delay(1000);
  Serial.flush(); 
  esp_deep_sleep_start();
  Serial.println("This will never be printed");
  
}

void lecture_donnee() {
  digitalWrite(LED_G, HIGH);
  delay(100);
  digitalWrite(LED_G, LOW);
  delay(100);
  girouette();
  //Toutes les secondes
  currentTime_P = currentTime_P + millis();
  Serial.println("currentTime_P - startTime_P: ");
  Serial.print(currentTime_P - startTime_P);
  Serial.print(" \n");
  Serial.println("period_P: ");
  Serial.print(period_P);
  Serial.print(" \n");
  if (currentTime_P - startTime_P >= period_P*100 /*temporary*/)//test whether the period has elapsed
  { 
    Serial.print("\n-------------------------------------\n");
    //Pluviomètre
    Serial.print("Quantité d'eau : ");
    Serial.print(calcul_quantite_eau());
    Serial.print(" mm \n");
    //LuxHumTemp
    calculateValues_BME_TSL();
    printValuesSerial();
    //Anemometre
    Anemo();
    //LoRa
    LoRa_Envoi();
    //Remise à 0 du compteur temporel
    startTime_P = currentTime_P;
  }
}

void loop(){
  //rien
}

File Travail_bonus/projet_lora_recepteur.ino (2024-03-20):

#include <SPI.h>
#include <LoRa.h>

#define ss 4 //18 avec module LoRa
#define rst 14
#define dio0 26

void setup() {
  Serial.begin(9600);
  delay(100);
  while (!Serial);

  Serial.println("LoRa Receiver");

  SPI.begin();
  LoRa.setPins(ss, rst, dio0);
  if (!LoRa.begin(868E6)) {
    Serial.println("Starting LoRa failed!");
    while (1);
  }
}

void loop() {
  // try to parse packet
  int packetSize = LoRa.parsePacket();
  if (packetSize) {
    // received a packet
    Serial.print("Received packet '");
    
    // read packet
    while (LoRa.available()) {
      Serial.print((char)LoRa.read());
    }

    // print RSSI of packet
    Serial.print("' with RSSI ");
    Serial.println(LoRa.packetRssi());
  }
}

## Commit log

2023-10-27 ADD A REPOSITORY : rapport de séance
2023-10-27 Ajout du rapport de seance du 27 oct 2023
2023-11-06 Create a directory for 3D models Add v1 GRAY_code_model stl file
    [v1_modelisation_grille_code_gray.stl]
2023-11-06 Ajout de la version V2 du plateau de la girouette.
    [v2_modelisation_grille_code_gray.stl]
2023-11-06 Ajout du rapport de seance du 6 nov 2023
2023-11-20 Add files via upload
    Ajout du rapport de seance du 20 11 2023
2024-02-16 Add last .stl
    [cylindre led-boite.stl, cylindre led-couvercle.stl]
2024-03-13 Add files via upload
    Use by factory to generate the R2R PCB
